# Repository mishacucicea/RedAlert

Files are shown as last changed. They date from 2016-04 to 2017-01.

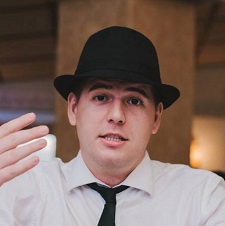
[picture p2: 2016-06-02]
API/RedAlert.API/RedAlert.API/Content/img/team/3.jpg

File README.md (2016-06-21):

# RedAlert
Extreme Feedback Device for anything!

LightFeeD is a visual feedback device for anything. Capable of producing the whole RGB range of colours and beeping sounds. It is controlled over the internet with a simple API that can be called virtually from anywhere with an Internet connection.  The device is powered with a standard USB charger. The brightness is auto-adjusted depending on your environment so it's not too bright at night, and not too dim during  the day.

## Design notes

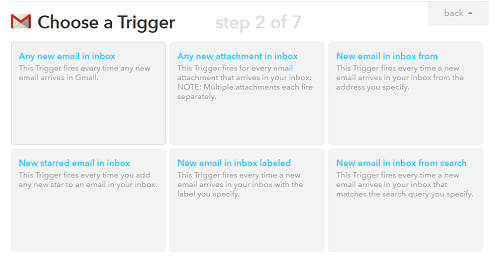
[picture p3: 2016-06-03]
API/RedAlert.API/RedAlert.API/Content/img/beforecompresing/choosetrigger.png

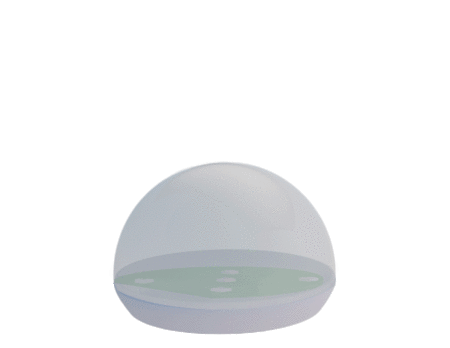
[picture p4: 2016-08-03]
API/RedAlert.API/RedAlert.API/Content/img/devicecomponent.gif

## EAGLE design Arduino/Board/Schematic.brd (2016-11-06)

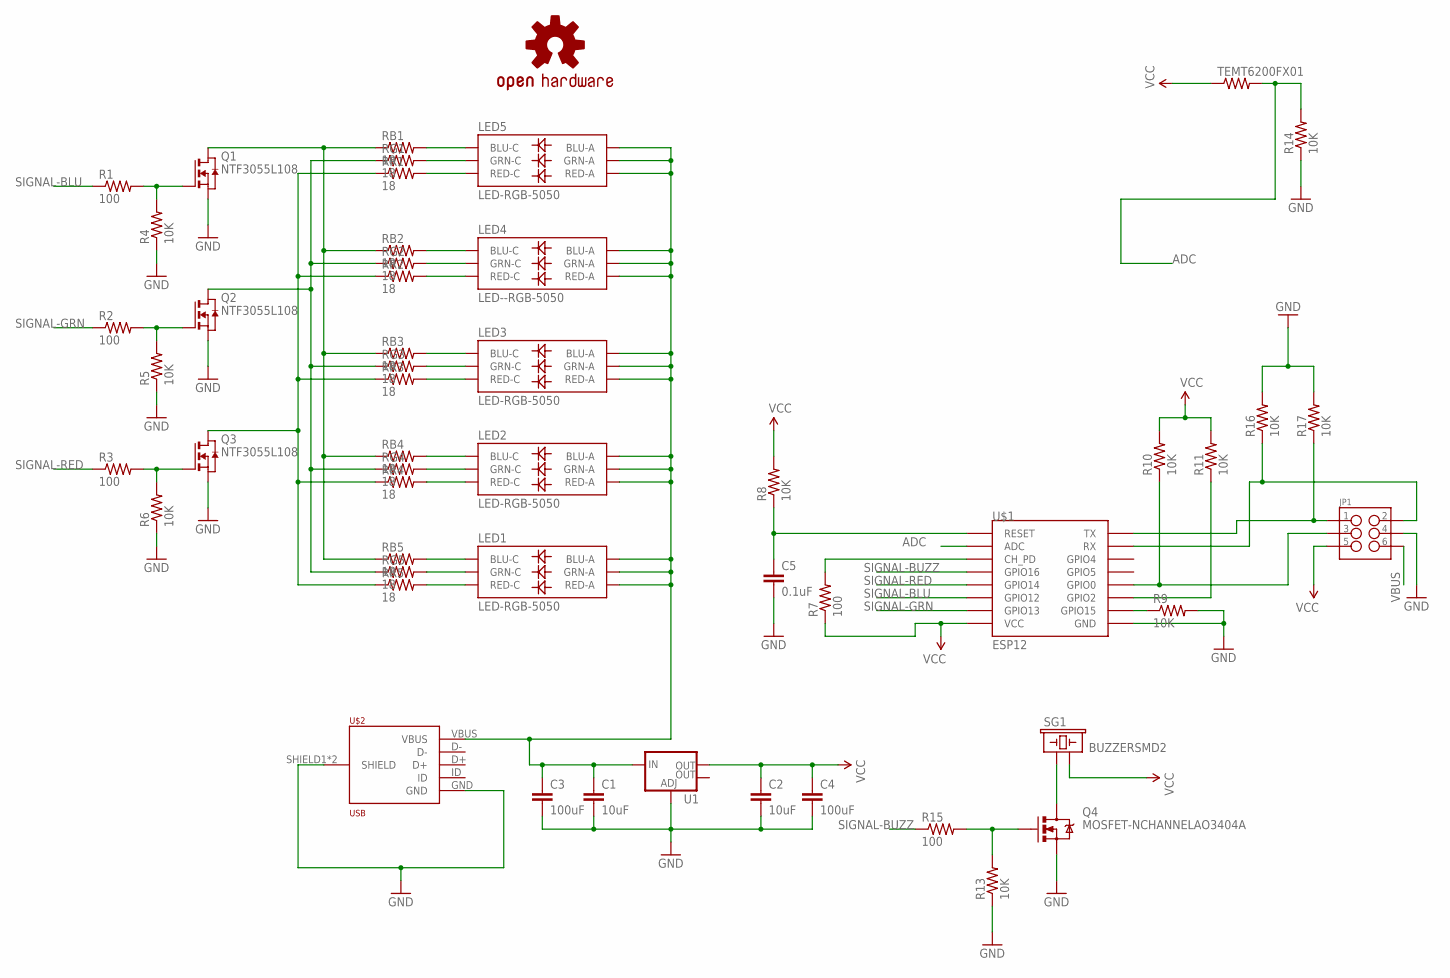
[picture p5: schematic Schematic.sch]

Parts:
C1, C2: 10uF; 0603-CAP
C3, C4: 100uF; 1206
C5: 0.1uF; 0603-CAP
JP1: M03X2POGO_PINS; 2X3_POGO
LED1, LED2, LED3, LED5: LED-RGB-5050; LED-TRICOLOR-5050
LED4: LED--RGB-5050; LED-TRICOLOR-5050
LOGO1: OSHW-LOGOM-COPPER; OSHW-LOGO-M_COPPER
Q1, Q2, Q3: NTF3055L108; SOT223HEAT
Q4: MOSFET-NCHANNELAO3404A; SOT23-3
R1, R2, R3, R7, R15: 100; 0805
R4, R5, R6, R8, R9, R10, R11, R13, R14, R16, R17: 10K; 0805
RB1, RB2, RB3, RB4, RB5: 18; 1206
RG1, RG2, RG3, RG4, RG5: 18; 1206
RR1, RR2, RR3, RR4, RR5: 18; 1206
SG1: BUZZERSMD2; BUZZER-CCV
TEMT6200FX01: RESISTOR0805-RES; 0805
U1: V_REG_LM1117SOT223; SOT223
U$1: ESP12
U$2: USB; MICRO-USB3065-30-00-A

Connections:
ADC: R14.2, TEMT6200FX01.2, U$1.ADC
GND: C1.2, C2.2, C3.2, C4.2, C5.2, JP1.P$4 (4), Q1.3 (S), Q2.3 (S), Q3.3 (S), Q4.2 (S), R4.1, R5.1, R6.1, R9.2, R13.1, R14.1, R16.2, R17.2, U1.1 (ADJ), U$1.GND, U$2.GND, U$2.SHIELD1 (SHIELD), U$2.SHIELD2 (SHIELD)
unnamed: LED5.4 (BLU-C), RB1.2
unnamed: LED1.4 (BLU-C), RB5.2
unnamed: LED5.6 (GRN-C), RG1.2
unnamed: Q1.2 (D), Q1.4 (D), Q1.P$1 (D), Q1.P$2 (D), Q1.P$3 (D), Q1.P$4 (D), Q1.P$5 (D), Q1.P$6 (D), Q1.P$7 (D), Q1.P$8 (D), Q1.P$9 (D), Q1.P$10 (D), Q1.P$11 (D), Q1.P$12 (D), Q1.P$13 (D), Q1.P$14 (D), Q1.P$15 (D), Q1.P$16 (D), Q1.P$17 (D), Q1.P$18 (D), Q1.P$19 (D), RB1.1, RB2.1, RB3.1, RB4.1, RB5.1
unnamed: LED5.5 (RED-C), RR1.2
unnamed: Q2.2 (D), Q2.4 (D), Q2.P$1 (D), Q2.P$2 (D), Q2.P$3 (D), Q2.P$4 (D), Q2.P$5 (D), Q2.P$6 (D), Q2.P$7 (D), Q2.P$8 (D), Q2.P$9 (D), Q2.P$10 (D), Q2.P$11 (D), Q2.P$12 (D), Q2.P$13 (D), Q2.P$14 (D), Q2.P$15 (D), Q2.P$16 (D), Q2.P$17 (D), Q2.P$18 (D), Q2.P$19 (D), RG1.1, RG2.1, RG3.1, RG4.1, RG5.1
unnamed: LED4.4 (BLU-C), RB2.2
unnamed: Q3.2 (D), Q3.4 (D), Q3.P$1 (D), Q3.P$2 (D), Q3.P$3 (D), Q3.P$4 (D), Q3.P$5 (D), Q3.P$6 (D), Q3.P$7 (D), Q3.P$8 (D), Q3.P$9 (D), Q3.P$10 (D), Q3.P$11 (D), Q3.P$12 (D), Q3.P$13 (D), Q3.P$14 (D), Q3.P$15 (D), Q3.P$16 (D), Q3.P$17 (D), Q3.P$18 (D), Q3.P$19 (D), RR1.1, RR2.1, RR3.1, RR4.1, RR5.1
unnamed: LED4.6 (GRN-C), RG2.2
unnamed: LED4.5 (RED-C), RR2.2
unnamed: LED3.4 (BLU-C), RB3.2
unnamed: LED3.6 (GRN-C), RG3.2
unnamed: LED3.5 (RED-C), RR3.2
unnamed: LED2.4 (BLU-C), RB4.2
unnamed: LED2.6 (GRN-C), RG4.2
unnamed: LED2.5 (RED-C), RR4.2
unnamed: LED1.6 (GRN-C), RG5.2
unnamed: LED1.5 (RED-C), RR5.2
unnamed: Q1.1 (G), R1.2, R4.2
unnamed: Q2.1 (G), R2.2, R5.2
unnamed: Q3.1 (G), R3.2, R6.2
unnamed: R7.2, U$1.CH_PD
unnamed: JP1.P$3 (3), R10.1, U$1.GPIO0
unnamed: C5.1, R8.1, U$1.RESET
unnamed: R11.1, U$1.GPIO2
unnamed: R9.1, U$1.GPIO15
unnamed: JP1.P$1 (1), R17.1, U$1.TX
unnamed: JP1.P$2 (2), R16.1, U$1.RX
unnamed: Q4.1 (G), R13.2, R15.2
unnamed: Q4.3 (D), SG1.+ (1)
SIGNAL-BLU: R1.1, U$1.GPIO12
SIGNAL-BUZZ: R15.1, U$1.GPIO16
SIGNAL-GRN: R2.1, U$1.GPIO13
SIGNAL-RED: R3.1, U$1.GPIO14
VBUS: C1.1, C3.1, JP1.P$6 (6), LED1.1 (GRN-A), LED1.2 (RED-A), LED1.3 (BLU-A), LED2.1 (GRN-A), LED2.2 (RED-A), LED2.3 (BLU-A), LED3.1 (GRN-A), LED3.2 (RED-A), LED3.3 (BLU-A), LED4.1 (GRN-A), LED4.2 (RED-A), LED4.3 (BLU-A), LED5.1 (GRN-A), LED5.2 (RED-A), LED5.3 (BLU-A), U1.3 (IN), U$2.VBUS
VCC: C2.1, C4.1, JP1.P$5 (5), R7.1, R8.2, R10.2, R11.2, SG1.- (2), TEMT6200FX01.1, U1.2 (OUT), U$1.VCC

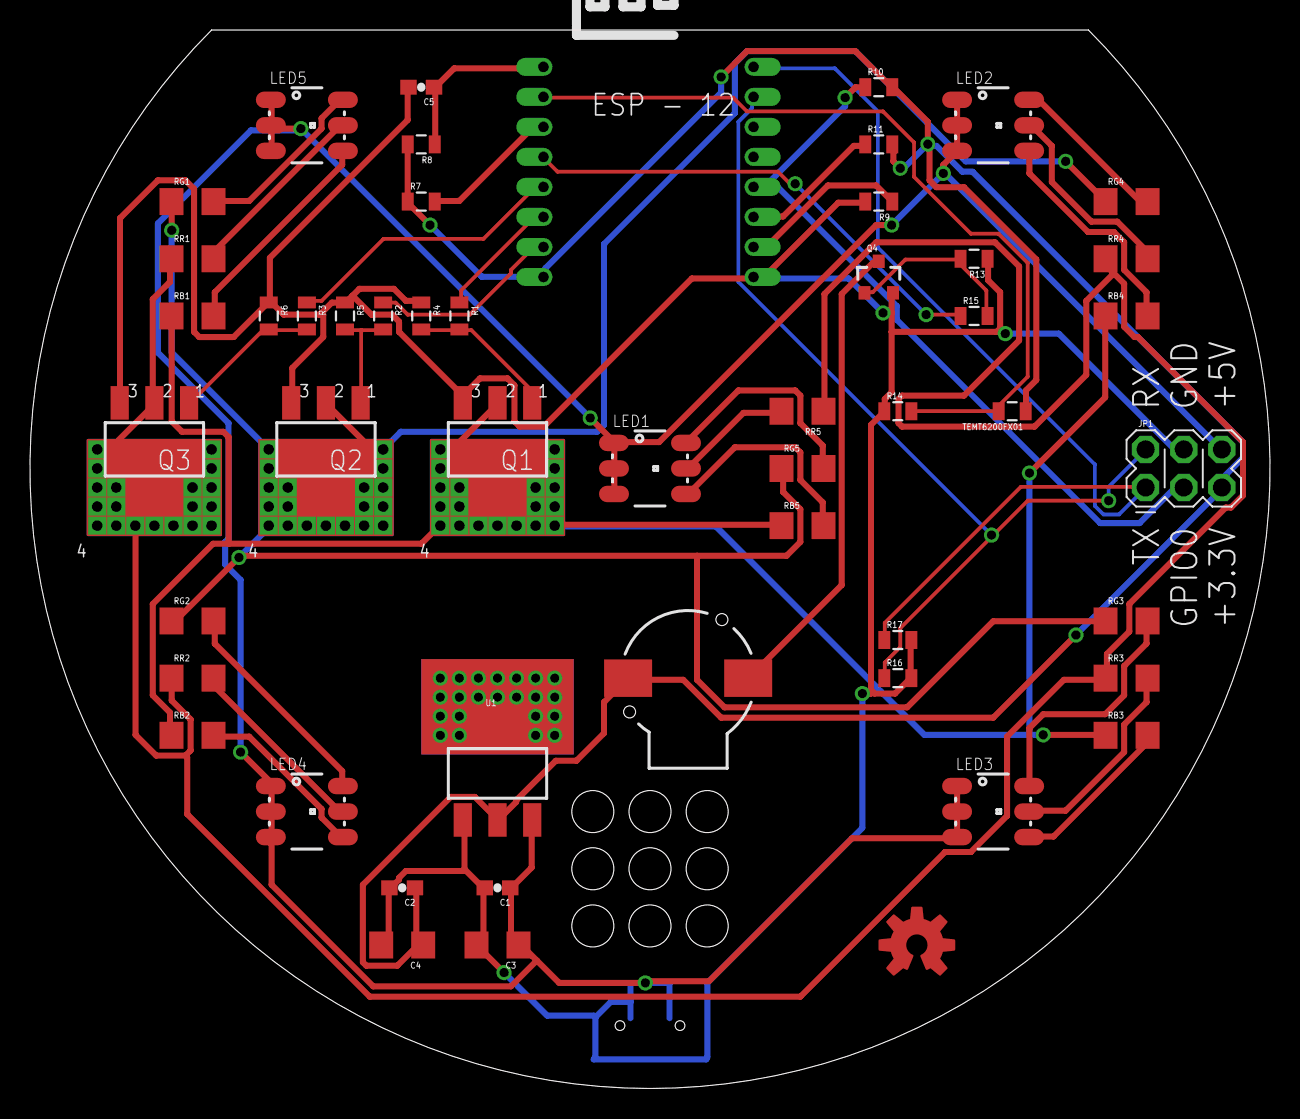
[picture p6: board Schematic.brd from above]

Board: 2 copper layers, 82.6 x 70.5 mm, 52 parts (1 on the bottom side), 38 nets.

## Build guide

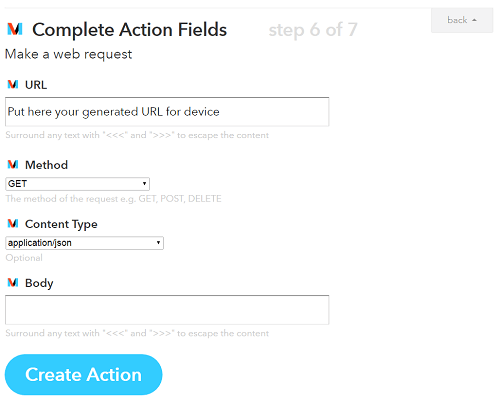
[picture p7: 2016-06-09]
API/RedAlert.API/RedAlert.API/Content/img/makerurl.png

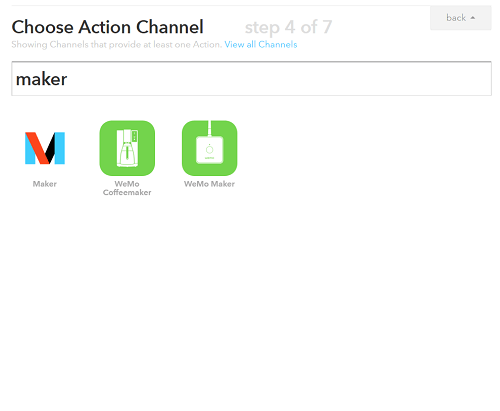
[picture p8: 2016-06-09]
API/RedAlert.API/RedAlert.API/Content/img/maker.png

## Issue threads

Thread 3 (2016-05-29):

Statuses are dropped

haiduc32, 2016-05-29:
Some of the statuses fail to be received by the device.

haiduc32, 2016-08-01:
closing this issue as did not notice this behaviour anymore.

Closed 2016-08-01.

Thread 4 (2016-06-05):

Handling transient connection problems

haiduc32, 2016-06-05:
The device should handle gracefully the following issues:

1. Wifi signal drops and restores.
2. Internet drops and restores.
3. After a power outage the device will restore faster then the WiFi router and should be able to reconnect to the router once it has booted up.

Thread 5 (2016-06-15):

Add Beeper

haiduc32, 2016-06-15:
add support for sound notifications. for the MVP that could be just a buzzer. need to also update the api to support the beeper.

haiduc32, 2016-07-19:
added to the V2 board design.

Closed 2016-07-19.

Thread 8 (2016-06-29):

Setup mode

haiduc32, 2016-06-29:
The setup mode is activated for 40 sec if the device has been setup already. This might not be enough for everybody.

The correct approach should be booting the device in both station and AP modes and letting the device be configured after it has connected  and started listening for messages. The setup mode should be disabled after a sensible amount of time ~2-5 minutes.

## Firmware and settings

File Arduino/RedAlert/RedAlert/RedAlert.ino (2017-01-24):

#include <Arduino.h>

#include <ESP8266WiFi.h>
#include <ESP8266mDNS.h>
#include <ESP8266httpUpdate.h>

#include <WiFiClientSecure.h>
#include <ESP8266HTTPClient.h>
#include "WiFiSetup.h"
#include "PubSubClient.h"
#include "Logging.h"
#include "ApiClient.h"

extern "C" {
#include "user_interface.h"
}

//TODO: don't forget to update!
char VERSION[] = "v3-dev-13";

unsigned long lastTimeCheck = 0;

//#define hubAddress "arduhub.azure-devices.net"
//#define deviceId "pocDevice"
//#define hubUser "arduhub.azure-devices.net/pocDevice"
//#define hubPass "SharedAccessSignature sr=arduhub.azure-devices.net%2fdevices%2fpocDevice&sig=ksApO9qnlvs%2bERTKS3qqvO0T7cRG2D1xhI7PiE5C8uk%3d&se=1490896187"
//#define hubTopic "devices/pocDevice/messages/devicebound/#"

#define SERIALSPEED 74880
//for Mini D1:
//#define SERIALSPEED 57600

//switch to enable support for secondary IoT Hub
#define USE_SECONDARY_HUB false

//switch to enable light dimming based on environment light
#define USE_LIGHT_LEVEL true

//define pins
#define RED_PIN 14
#define BLUE_PIN 13
#define GREEN_PIN 12

#define BUZZ_PIN 16

#define PATTERN_CONTINUOUS 0
#define PATTERN_WAVES 1

//ref: https://github.com/oh1ko/ESP82666_OLED_clock/blob/master/ESP8266_OLED_clock.ino

//ref: https://github.com/chriscook8/esp-arduino-apboot/blob/master/ESP-wifiboot.ino

WiFiClientSecure wclient;
WiFiClientSecure secondarywClient;
PubSubClient client(wclient);
PubSubClient secondaryClient(secondarywClient);

bool hasColor = false;
byte pattern;
int patternStage;
byte color[3];
int lastLight;

/*
 * Expands a 8 bit number to 10bits
 */
int expand10(byte value) {
  //ROL 2 and then ROR 6 to add the 2 upper bits as the lower ones
  int expanded = (value<<2) + (value>>6);
  return expanded;
}

void setColor(float r, float g, float b) {
  if (USE_LIGHT_LEVEL) {
    float red = r;
    float green = g;
    float blue = b;

    if (lastLight > 1024 / 10 * 9) {
      //do nothing
    } else if (lastLight > 1024 / 10 * 8) {
      red = red / 10 * 9;
      green = green / 10 * 9;
      blue = blue / 10 * 9;
    } else if (lastLight > 1024 / 10 * 7) {
      red = red / 10 * 8;
      green = green / 10 * 8;
      blue = blue / 10 * 8;
    } else if (lastLight > 1024 / 10 * 6) {
      red = red / 10 * 7;
      green = green / 10 * 7;
      blue = blue / 10 * 7;
    } else if (lastLight > 1024 / 10 * 5) {
      red = red / 10 * 6;
      green = green / 10 * 6;
      blue = blue / 10 * 6;
    } else if (lastLight > 1024 / 10 * 4) {
      red = red / 10 * 5;
      green = green / 10 * 5;
      blue = blue / 10 * 5;
    } else if (lastLight > 1024 / 10 * 3) {
      red = red / 10 * 4;
      green = green / 10 * 4;
      blue = blue / 10 * 4;
    } else if (lastLight > 1024 / 10 * 2) {
      red = red / 10 * 3;
      green = green / 10 * 3;
      blue = blue / 10 * 3;
    } else if (lastLight > 1024 / 10) {
      red = red / 10 * 2;
      green = green / 10 * 2;
      blue = blue / 10 * 2;
    } else {
      red = red / 10;
      green = green / 10;
      blue = blue / 10;
    }

    analogWrite(RED_PIN, (int)red);
    analogWrite(GREEN_PIN, (int)green);
    analogWrite(BLUE_PIN, (int)blue);
  } else {
    analogWrite(RED_PIN, (int)r);
    analogWrite(GREEN_PIN, (int)g);
    analogWrite(BLUE_PIN, (int)b);
  }
}

void commandCallback(char* topic, byte* payload, unsigned int length) {
  Debug("Entered commandCallback");
  //this is the new format:
  //check that the length is 9 and message code is 1
  if (length == 9 && payload[0] == 1) {
    //1 byte is the type of the message
    //3 bytes is the RGB value
    //1 bytes is the pattern number - not supported yet
    //4 bytes is the timeout - not supported yet
    
    hasColor = true;
    pattern = payload[4];
    
    patternStage = 0;
    color[0] = payload[1];
    color[1] = payload[2];
    color[2] = payload[3];

    setColor(expand10(color[0]), expand10(color[1]), expand10(color[2]));
  }
  else {

    // handle message arrived
    String msg = "";
    for (int i = 0; i < length; i++) {
      msg += (char)payload[i];
    }
  
    Info2("Message received: ", msg);
  }
}

void tryUpdate() {
  t_httpUpdate_return ret = ESPhttpUpdate.update("lightfeed.eu", 80, "/api/iot/update", VERSION);
  switch(ret) {
      case HTTP_UPDATE_FAILED: {
            Debug("[update] Update failed.");

            int lastError = ESPhttpUpdate.getLastError();
            Debug2("Last error: ", lastError);
            String lastErrorString = ESPhttpUpdate.getLastErrorString();
            Debug2("Last error: ", lastErrorString);
        }
          break;
      case HTTP_UPDATE_NO_UPDATES:
          Debug("[update] Update no Update.");
          break;
      case HTTP_UPDATE_OK:
          Debug("[update] Update ok."); // may not called we reboot the ESP
          break;
  }
}

void setup() {
  //need for debugging and communication with the slave module
  Serial.begin(SERIALSPEED);
  
  //testing the free memory TODO: monitor free memory and send as telemetry?
  /*
  uint32_t free = 0;
  {
    String s = "";
    for (int i = 0; i < 10; i++) {
      s += "test";
      free = system_get_free_heap_size();
      Debug(free);
      //s = "mama";
      delay (1000);
    }
    s = "";
    free = system_get_free_heap_size();
    Debug(free);
  }
  free = system_get_free_heap_size();
  Debug(free);
  */
  
  //start the eeprom and wait 10 msecs for safety
  EEPROM.begin(512);
  delay(10);

  pinMode(RED_PIN, OUTPUT);
  pinMode(GREEN_PIN, OUTPUT);
  pinMode(BLUE_PIN, OUTPUT);
  
  pinMode(BUZZ_PIN, OUTPUT);
  
  //analogWriteFreq(2000);
  //analogWrite(BUZZ_PIN, 512);
  //DOES NOT WORK: tone(BUZZ_PIN, 2000); 
  //setColor(1023, 1023, 1023);
  //while(true) {}
  
  //for pin testing
  //while(true)
  {
    /*
    setColor(0, 0, 0);
    //delay(0);
    int light = analogRead(A0);

    int red = 1023;
    int green = 0;
    int blue = 0;
    
    
    
    setColor(red, green, blue);
    delay(1000);
    */
    setColor(1023, 1023, 1023);
    delay(1000);
  }

  setColor(0, 0, 0);

  Debug2("Version: ", VERSION);
  
  //initializing the wifi module
  wifiSetup.eepromOffset = 0;
  wifiSetup.loadStationSettings();

  int setupModeTimeout = 40;

  while (true) {
    wifiSetup.scanNetworks();
  
    //enter in AP mode (name should auto setup)
    Debug("Entering AP mode");
    wifiSetup.setupAP();
    delay(100);
  
    //wait ~40 sec for connections
    unsigned long now = millis();
  
    Debug("Enter setup mode for at least 40 seconds");
    do  {
      wifiSetup.beginSetupMode(setupModeTimeout);
    } while (!wifiSetup.getHasSettings());
  
    wifiSetup.endSetupMode();
    
    Debug("Moving to station mode.");
    //TODO: if could not enter station mode (no SSID, no network, errors connecting, etc,
    //then go back to setup mode
    //time to move to Station mode
    if (wifiSetup.stationMode()) {
      break;
    }
    else {
      //cycle through the RGB colours to denote there is a problem with WiFI
      setColor(1023, 0, 0);
      setColor(0, 1023, 0);
      setColor(0, 0, 1023);
      setColor(0, 0, 0);
      //if wifi connection failed, go back to setup mode
      setupModeTimeout = 60;
      continue;
    }
  }

  //TODO: do we need this line?
  configTime(3 * 3600, 0, "pool.ntp.org", "time.nist.gov");
}

//unsigned long last1000;
int ticksTo10sCounter = 0;

void loop() {
  unsigned long now = millis();
  //TODO: fix bug: after 47 days the now will reset to 0
  
  //at start, or once each day
  if (lastTimeCheck == 0 || now - lastTimeCheck > 24*3600*1000 || now < lastTimeCheck) {
    lastTimeCheck = now;

    //first we have to check for the update, as the device will restart after update
    tryUpdate();
    
    if (!apiClient.getCredentials(wifiSetup.getApiKey())) {
      //reset 
      lastTimeCheck = 0;
      
      //cycle through the RGB colours to denote there is a problem with WiFI
      setColor(1023, 0, 0);
      setColor(0, 1023, 0);
      setColor(0, 0, 1023);
      setColor(0, 0, 0);
      
      return;
    }
    
    //TODO: so what happens after 24H?...
    
    Debug("Setting server for MQTT");
    //this will set the address of the hub and port on which it communicates
    client.setServer(apiClient.getHubAddress(), 8883);
  
    Debug("Setting commandCallback for MQTT");
    client.setCallback(commandCallback);
    
    if (apiClient.hasSecondary()) {
      secondaryClient.setServer(apiClient.getHubAddress2(), 8883);
      secondaryClient.setCallback(commandCallback);
    }
  }

  //looks like making the checks so much more often, the MQTT library doesn't fail so much..
  //looks like there might be a problem if there are 2 or more MQTT messages to read fro on a MQTT loop()
  //every second
  //if (last1000 == 0 || now - last1000 >= 1000 || now < last1000) {
    //last1000 = now;
    
    //Debug("Checking for wifi connected");
    if (WiFi.status() == WL_CONNECTED) {
      //Debug("WiFi is connected");
      if (!client.connected()) {
        Debug("MQTT connecting..");
        if (client.connect(apiClient.getDeviceId(), apiClient.getHubUser(), apiClient.getHubPass())) {
          //TODO: log connected status
          Debug("MQTT connected.");
  
          //client.publish("outTopic", "test");
          Debug("Subscribing to the MQTT topic and QOS1");
          client.subscribe(apiClient.getHubTopic(), 1);
          Info("Ready to receive messages.");
        } else {
          Debug("Could not connect :(");
        }
      }
      
      if (USE_SECONDARY_HUB && apiClient.hasSecondary() && !secondaryClient.connected()) {
        Debug("Secondary MQTT connecting..");
        if (secondaryClient.connect(apiClient.getDeviceId2(), apiClient.getHubUser2(), apiClient.getHubPass2())) {
          //TODO: log connected status
          Debug("Secondary MQTT connected.");
  
          //client.publish("outTopic", "test");
          Debug("Subscribing to the Secondary MQTT topic and QOS1");
          secondaryClient.subscribe(apiClient.getHubTopic2(), 1);
          Info("Secondary Ready to receive messages.");
        } else {
          Debug("Secondary could not connect :(");
        }
      }
      
      //Debug("checking if MQTT is connected");
      if (client.connected()) {
        //Debug("MQTT is connected!");
        if (!client.loop()) {
          Debug("MQTT failed to loop");
          Debug2("MQTT state: ", client.state());
        }
      }
      
      if (USE_SECONDARY_HUB && apiClient.hasSecondary() && secondaryClient.connected()) {
        //Debug("MQTT is connected!");
        if (!secondaryClient.loop()) {
          Debug("Second MQTT failed to loop");
          Debug2("Second MQTT state: ", secondaryClient.state());
        }
      }
    } else {
      Debug("WiFi is not connected!");

      //TODO: wifi reconnect logic in here?
    }
  //}
  


  //ideally will be executed every 20ms, but we don't really care about accuracy in here
  if (hasColor = true) {
    if (pattern == PATTERN_WAVES) {
      patternStage = ++patternStage % 400;
      
      //total pattern cycle is 4 sec - max stage = 400
      int red = expand10(color[0]);
      int green = expand10(color[1]);
      int blue = expand10(color[2]);

      float redF = 0.0;
      float greenF = 0.0;
      float blueF = 0.0;
  
      if (patternStage == 0) {
        //it means that the output will be blank
        //we can read ADC here without anyone noticing!
        
        checkBrightness();
      }
      
      if (patternStage < 200) {
        redF = ((float)red / 200 * patternStage);
        greenF = ((float)green / 200 * patternStage);
        blueF = ((float)blue / 200 * patternStage);
      } else {
        redF = ((float)red / 200 * (400 - patternStage));
        greenF = ((float)green / 200 * (400 - patternStage));
        blueF = ((float)blue / 200 * (400 - patternStage));
      }

      setColor(redF, greenF, blueF);
    }
  }
  
  delay(20);
}

/* warning: checking brightness delays the clock by a few milliseconds */
void checkBrightness() {
  if (USE_LIGHT_LEVEL) {
    lastLight = analogRead(A0);
    Debug2("Brightness level: ", lastLight);
  }
}

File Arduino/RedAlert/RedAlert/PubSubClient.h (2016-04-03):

/*
 PubSubClient.h - A simple client for MQTT.
  Nick O'Leary
  http://knolleary.net
*/

#ifndef PubSubClient_h
#define PubSubClient_h

#include <Arduino.h>
#include "IPAddress.h"
#include "Client.h"
#include "Stream.h"
#include "Logging.h"

#define MQTT_VERSION_3_1      3
#define MQTT_VERSION_3_1_1    4

// MQTT_VERSION : Pick the version
//#define MQTT_VERSION MQTT_VERSION_3_1
#ifndef MQTT_VERSION
#define MQTT_VERSION MQTT_VERSION_3_1_1
#endif

// MQTT_MAX_PACKET_SIZE : Maximum packet size
#ifndef MQTT_MAX_PACKET_SIZE
#define MQTT_MAX_PACKET_SIZE 256//128
#endif

// MQTT_KEEPALIVE : keepAlive interval in Seconds
#ifndef MQTT_KEEPALIVE
#define MQTT_KEEPALIVE 15
#endif

// MQTT_SOCKET_TIMEOUT: socket timeout interval in Seconds
#ifndef MQTT_SOCKET_TIMEOUT
#define MQTT_SOCKET_TIMEOUT 15
#endif

// MQTT_MAX_TRANSFER_SIZE : limit how much data is passed to the network client
//  in each write call. Needed for the Arduino Wifi Shield. Leave undefined to
//  pass the entire MQTT packet in each write call.
//#define MQTT_MAX_TRANSFER_SIZE 80

// Possible values for client.state()
#define MQTT_CONNECTION_TIMEOUT     -4
#define MQTT_CONNECTION_LOST        -3
#define MQTT_CONNECT_FAILED         -2
#define MQTT_DISCONNECTED           -1
#define MQTT_CONNECTED               0
#define MQTT_CONNECT_BAD_PROTOCOL    1
#define MQTT_CONNECT_BAD_CLIENT_ID   2
#define MQTT_CONNECT_UNAVAILABLE     3
#define MQTT_CONNECT_BAD_CREDENTIALS 4
#define MQTT_CONNECT_UNAUTHORIZED    5

#define MQTTCONNECT     1 << 4  // Client request to connect to Server
#define MQTTCONNACK     2 << 4  // Connect Acknowledgment
#define MQTTPUBLISH     3 << 4  // Publish message
#define MQTTPUBACK      4 << 4  // Publish Acknowledgment
#define MQTTPUBREC      5 << 4  // Publish Received (assured delivery part 1)
#define MQTTPUBREL      6 << 4  // Publish Release (assured delivery part 2)
#define MQTTPUBCOMP     7 << 4  // Publish Complete (assured delivery part 3)
#define MQTTSUBSCRIBE   8 << 4  // Client Subscribe request
#define MQTTSUBACK      9 << 4  // Subscribe Acknowledgment
#define MQTTUNSUBSCRIBE 10 << 4 // Client Unsubscribe request
#define MQTTUNSUBACK    11 << 4 // Unsubscribe Acknowledgment
#define MQTTPINGREQ     12 << 4 // PING Request
#define MQTTPINGRESP    13 << 4 // PING Response
#define MQTTDISCONNECT  14 << 4 // Client is Disconnecting
#define MQTTReserved    15 << 4 // Reserved

#define MQTTQOS0        (0 << 1)
#define MQTTQOS1        (1 << 1)
#define MQTTQOS2        (2 << 1)

#ifdef ESP8266
#include <functional>
#define MQTT_CALLBACK_SIGNATURE std::function<void(char*, uint8_t*, unsigned int)> callback
#else
#define MQTT_CALLBACK_SIGNATURE void (*callback)(char*, uint8_t*, unsigned int)
#endif

class PubSubClient {
private:
   Client* _client;
   uint8_t buffer[MQTT_MAX_PACKET_SIZE];
   uint16_t nextMsgId;
   unsigned long lastOutActivity;
   unsigned long lastInActivity;
   bool pingOutstanding;
   MQTT_CALLBACK_SIGNATURE;
   uint16_t readPacket(uint8_t*);
   boolean readByte(uint8_t * result);
   boolean readByte(uint8_t * result, uint16_t * index);
   boolean write(uint8_t header, uint8_t* buf, uint16_t length);
   uint16_t writeString(const char* string, uint8_t* buf, uint16_t pos);
   IPAddress ip;
   const char* domain;
   uint16_t port;
   Stream* stream;
   int _state;
public:
   PubSubClient();
   PubSubClient(Client& client);
   PubSubClient(IPAddress, uint16_t, Client& client);
   PubSubClient(IPAddress, uint16_t, Client& client, Stream&);
   PubSubClient(IPAddress, uint16_t, MQTT_CALLBACK_SIGNATURE,Client& client);
   PubSubClient(IPAddress, uint16_t, MQTT_CALLBACK_SIGNATURE,Client& client, Stream&);
   PubSubClient(uint8_t *, uint16_t, Client& client);
   PubSubClient(uint8_t *, uint16_t, Client& client, Stream&);
   PubSubClient(uint8_t *, uint16_t, MQTT_CALLBACK_SIGNATURE,Client& client);
   PubSubClient(uint8_t *, uint16_t, MQTT_CALLBACK_SIGNATURE,Client& client, Stream&);
   PubSubClient(const char*, uint16_t, Client& client);
   PubSubClient(const char*, uint16_t, Client& client, Stream&);
   PubSubClient(const char*, uint16_t, MQTT_CALLBACK_SIGNATURE,Client& client);
   PubSubClient(const char*, uint16_t, MQTT_CALLBACK_SIGNATURE,Client& client, Stream&);

   PubSubClient& setServer(IPAddress ip, uint16_t port);
   PubSubClient& setServer(uint8_t * ip, uint16_t port);
   PubSubClient& setServer(const char * domain, uint16_t port);
   PubSubClient& setCallback(MQTT_CALLBACK_SIGNATURE);
   PubSubClient& setClient(Client& client);
   PubSubClient& setStream(Stream& stream);

   boolean connect(const char* id);
   boolean connect(const char* id, const char* user, const char* pass);
   boolean connect(const char* id, const char* willTopic, uint8_t willQos, boolean willRetain, const char* willMessage);
   boolean connect(const char* id, const char* user, const char* pass, const char* willTopic, uint8_t willQos, boolean willRetain, const char* willMessage);
   void disconnect();
   boolean publish(const char* topic, const char* payload);
   boolean publish(const char* topic, const char* payload, boolean retained);
   boolean publish(const char* topic, const uint8_t * payload, unsigned int plength);
   boolean publish(const char* topic, const uint8_t * payload, unsigned int plength, boolean retained);
   boolean publish_P(const char* topic, const uint8_t * payload, unsigned int plength, boolean retained);
   boolean subscribe(const char* topic);
   boolean subscribe(const char* topic, uint8_t qos);
   boolean unsubscribe(const char* topic);
   boolean loop();
   boolean connected();
   int state();
};


#endif

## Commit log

2016-03-03 first commit of the arduino code
2016-03-03 Device Web UI
2016-03-03 Added new controller for MVC and view for adding new device
2016-03-04 various...
    what’s left is connecting to the api to get the keys, and connecting to
    the hub. the rest is written but not tested.
2016-03-05 Arduino - serial receive.
2016-03-28 added the board
    [Schematic.brd, Schematic.sch]
2016-05-27 work on forming the message for the device
2016-05-29 working on the device firmware
    [Schematic.brd]
2016-06-02 building the connection string for the device
2016-06-02 updated the device HTML template
2016-06-02 creating api methods for device connection
2016-06-03 added new logo and fix device template widht
2016-06-06 binding the DeviceIdentity controller to the database.
2016-06-07 changing the functionality for device registration and device getting connection info
2016-06-08 fixed the error on device registration page
2016-06-08 debugging the device registration process
2016-06-11 fixed authentication api requests
    [RedAlert.ino]
2016-06-25 Redirect to Error view in case of error. Separated header and footer into individual views.
2016-06-25 fixed the firmware for OTA
    [RedAlert.ino]
2016-06-25 fixed the firmware for OTA (yet again..)
    [RedAlert.ino]
2016-06-25 updated firmware to correctly handle the WAVES pattern.
    [RedAlert.ino]
2016-06-26 Added DeviceList method and other minor fixes. Removed DeviceIdentityController as it was no longer used.
2016-06-26 Narrow navigation menu. Adding device list and device details views and actions.
2016-06-29 Added device name and parameter entry for mood page.
2016-06-29 Added extra bits of loging for device authentication
2016-06-29 fixed sneaky bug on device authentication after the first message was sent to device.
2016-06-30 added reset button
2016-06-30 Setting device key on details.
2016-06-30 Changed device ID for demo.
2016-06-30 Adjusted device id for mood.
2016-07-07 added layout for list of devices
2016-07-08 pcb upgrade
    changed:
    - bigger (size) resistors for LEDs
    - changed MOSFETs for more power
    - added ambient light sensors
    [Schematic.brd, Schematic.sch]
2016-07-08 added buzzer
    added buzzer and holes for air flow
    [Schematic.brd, Schematic.sch]
2016-07-09 updated firmware with newer Arduino Core version
2016-07-11 updated the board design
    updated to the requirements in the https://trello.com/c/WxGEJiPR
    [Schematic.brd, Schematic.sch]
2016-07-12 small fixes to the board.
    [Schematic.brd, Schematic.sch]
2016-07-31 refactoring arduino code
2016-08-01 Layout changes on Register device view.
2016-08-01 added colour cycling in case of problems.
    [RedAlert.ino]
2016-08-01 added per device SSID generation
2016-08-02 Reset sender/device keys.
2016-08-02 Remove device (from the MyDevices page).
2016-08-02 Merge branch 'arduino-UX'
    # Conflicts:
    # Arduino/RedAlert/RedAlert/WiFiSetup.cpp
2016-08-04 Temporary added AllowAnonymous on BaseController. Hub device Id is now hidden from device details.
2016-08-08 - added Online/Offline indicator for the device list. - adjusted designto be centered.
2016-08-11 Add trace debug to see why NLog is not working.
2016-09-16 add email field on register & added new page for adding new device to user
2016-09-16 Revert "add email field on register & added new page for adding new device to user"
    This reverts commit 49b9a230bd3d51e079dd35f5bdd26ddc3e518950.
2016-11-06 updated board (Rev. 3)
    [Schematic.brd, Schematic.sch]

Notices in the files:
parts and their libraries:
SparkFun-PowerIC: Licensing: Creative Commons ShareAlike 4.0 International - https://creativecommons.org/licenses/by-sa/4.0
